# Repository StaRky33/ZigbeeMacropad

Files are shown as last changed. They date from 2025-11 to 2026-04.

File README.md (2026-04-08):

# 🧠 Zigbee Macropad (ESP32-C6)

A compact **16-key Zigbee macropad** powered by the an **ESP32-C6**, designed for integration with **Home Assistant (ZIGBEE2MQTT)**.  
It provides tactile mechanical key input, configurable LED feedback, and a fully 3D-printed case.
It gives 3 sorts of inputs, single click, double clicks and long click to add into any automation to control device remotely.

---

## ⚙️ Hardware

| Component | Description |
|---|---|
| **MCU** | Seeed Studio XIAO ESP32C6 |
| **Switches** | 16 x Cherry MX Red (linear) |
| **Battery** | 1 x 3.7V 1000mAh Lipo 603048 |
| **Button** | 6 mm tactile push button (BOOT / Reset) |
| **Power switch** | 13 mm by 8.5 mm on/off slide switch |
| **Magnets** | 4 x 10 mm × 2 mm neodymium discs |
| **Threaded inserts** | 5 x M2.5 heat-set brass inserts |
| **Screws** | 4 x M2.5 × 5 mm machine screws |
| **Didodes**| 16 x 1N4148 Small Signal Fast Switching Diodes |
| **External RGB Led**| 1 x 4 pins 5mm RGB Led Common Cathode |
| **220 ohm resistor**| 3 x 220 ohm resistor |
| **Case** | 3D-printed PLA enclosure (about 79g with cap switches and supports) |
| **Switches cap**| 16 x 3D-printed in PLA less than 18g total |

---

## 🧩 3D-Printed Parts

Designed and customized in **Tinkercad**, printed with **Centauri Carbon and transparent PLA**.  
Printed at 0.2 mm layer height, 15–20% infill, no supports required.

Files available on Github or in Printables [here](https://www.printables.com/model/1496778-zigbee-macropad-16-buttons-esp32c6) or Thingiverse [there](https://www.thingiverse.com/thing:7215442).

### 🔗 Remixed Models
- [16 Keys Macropad](https://www.printables.com/model/140766-16-keys-macropad)  
- [Simple Cherry MX Keycap](https://www.printables.com/model/118708-simple-cherry-mx-keycap)

---
### ⚡ Easy Install (Recommended)
No tools needed — flash directly from your browser:  
👉 [Web Flasher](https://starky33.github.io/ZigbeeMacropad)  
Works on Chrome and Edge only. Connect your ESP32-C6 via USB first.

## 💻 Code

Development began in **Arduino IDE**, later migrated to **VS Code with ESP-IDF v5.3.4** for Zigbee and multitasking support.

### 🧠 Software Stack
- **Framework:** ESP-IDF v5.3.4  
- **Zigbee SDK:** [Espressif ESP-Zigbee-SDK](https://github.com/espressif/esp-zigbee-sdk)  
- **Zigbee Role:** Router / End Device  
- **Endpoint Type:** Custom Endpoint and clusters

### 🔧 Functionality
- 16 GPIO-connected keys with **single**, **double**, and **long press** detection
- **LED feedback** color for each type of press  
- **LED feedback** brightness controlled via Zigbee “brightness” attribute  
- **BOOT button** triggers Zigbee factory reset and new pairing mode  
- **ON/OFF switch** physical button to turn everything off and recharge the batteries
- **Blinking red LED** indicates pairing state  
- **Debounce and ISR-driven** button logic for reliability  
- **Deep sleep** after 20 sec to save battery time  

---

## 🗺️ Circuit Schematic
[Link to circuit] (https://www.circuit-diagram.org/editor/c/4865aa39fb9b4097a776ca335299ee0a)

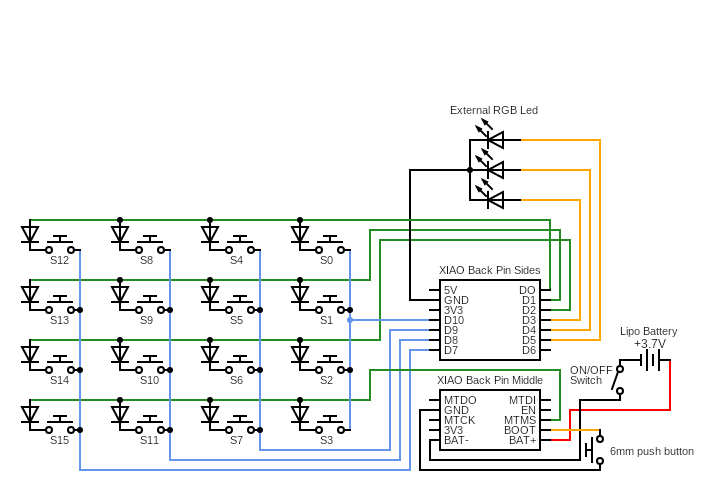
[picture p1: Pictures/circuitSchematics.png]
Circuit Schematics

---

## 💰 Price Breakdown
Calculated from **unit price × quantity used**:

| Item | Pack Price | Qty Used | Unit Cost | Cost Used |
|---|---|---|---|---|
| XIAO Esp32C6 | 8.04 € / 1 | 1 | 8.04 € | **8.04 €** |
| Mechanical Switches | 8.18 € / 20 | 16 | 0.41 € | **6.54 €** |
| Diodes 1N4148 | 1.20 € / 100 | 16 | 0.01 € | **0.19 €** |
| Magnets | 4.99 € / 50 | 4 | 0.10 € | **0.40 €** |
| M2.5 Inserts | 10.79 € / 600 | 5 | 0.018 € | **0.09 €** |
| Transparent PLA | 16.00 € / 1 kg | 100 g | 1.60 € | **1.60 €** |
| 6mm Push Button | 2.23 € / 50 | 1 | 0.045 € | **0.04 €** |
| ON/OFF Switch | 1.41 € / 5 | 1 | 0.28 € | **0.28 €** |
| 3.7V 1000mAh 603048 Lipo Battery  | 9.49 € / 3 | 1 | 3.16 € | **3.16 €** |
| External 5mm RGB Led Common Cathode | 1.29 € / 50 | 1 | 0.03 € | ** 0.03 €** |
| 220ohm resistore | 0,93€ / 100 | 3 | 0.028 € | ** 0.03 €** |
   
### **➡️ Total Cost per Macropad: 20.42 €**

---

## ⚠️ Note about the ESP32-C6 board

Using the Seeed Studio XIAO ESP32C6 is a breeze. 

The documentation is excellent.
The chip already contains a BMS so you can plug the battery directly in and charge it with USB-C

---

## 🧰 Build Instructions

### 🪛 1. Print and Prepare the Case
- Print all parts. Only the remix part is present in github, everything else can be found on printables.
- Verify that magnets, switches, and PCB fit snugly before final assembly.
- Insert **M2.5 heat-set inserts** into the designated mounting points using a soldering iron at ~200 °C.

### ⚡ 2. Mount the Components
- **Cherry MX switches**: press-fit into the 16-slot plate, solder to perfboard or PCB or with simple wires.
- **XIAO ESP32C6**: simply clip in place with any fixation. You might need to push a bit hard.
- **6 mm BOOT button**: mount to a small hole on the side (for Zigbee reset). Add some glue from glue gun.
- **Power switch**: connect inline with battery’s.
- **Battery holder**: Press fit battery inside. The EBL battery have a builtin BMS so I glue them in their slot with the micro usb accessible outside.
- **Magnets**: press-fit into the lid and base for a secure snap fit. You can add super glue to make sure they don't move.

### 🔋 3. Wiring Overview
| Connection | Description |
|---|---|
| **GPIO 0(D0),1(D1),2(D2),4(MTMS) and 18(D10),19(D9),20(D8),17(D7)** | 0,1,2,4 are for Rows, 18,19,20,17 are for Columns. Follow the wiring diagram. Connect 4 wires to columns and to one side of every switch. Connect all diodes to the other side of the switch. Make sure the black marker is connected to the switch and the other end is connected to the 3 other diodes on the same row. |
| **GPIO 9(BOOT)** | BOOT / Reset button. Connect to one side of the 6mm button and the other to GND. |
| **GPIO 21(D3),22(D4),23(D5)** | RGB Led is connected to 220 ohm resistor and to ground. The longest pin is ground. The side with a single pin it's R that goes into D5, then D4 for G, then D3 for B |
| **Battery pack** | Bat+ and Bat- on the ESP32 with bat + in line with the On/Off switch. |
| **On/Off switch** | Inline with battery lead. |

### 🔧 4. Flash the Firmware
1. Install **ESP-IDF v5.3.4** (or newer).  
2. Clone or copy the project to your workspace.  
3. Build and flash:
   ```bash
   idf.py set-target esp32c6
   idf.py build
   idf.py flash monitor
The device will start blinking red to indicate Zigbee pairing mode.

---

## 🔗 Pair with Home Assistant

Add macropad.mjs file to config/zigbee2mqtt/external_converters (if folder does not exist create it).
Then reboot Zigbee2MQTT in Settings/Add-ons/Zigbee2MQTT/Info and press Restart (takes 30 seconds)
In Home Assistant, open Settings → Devices & Services → Zigbee2MQTT → Permit join.
Test button clicks (single, double, hold) — LED flashes will reflect the button type.
You can now create an automation based on the button clicks.

The cluster ID is defined as a single constant `MACROPAD_CLUSTER` at the top 
of `macropad.mjs`. If it ever stops working after a z2m update, check the 
z2m logs for the cluster number and update that one constant.
To find your cluster name, simply check the logs in Zigbee2MQTT. I prefer checking them in the add-on directly since there is more information.
Add-on logs accessible in Settings/Add-ons/Zigbee2MQTT/Log

---

## ✨ Features Summary

🔘 16 mechanical switches with multiple click detection
🔋💤 Deep Sleep feature turning on after 2 minutes to save battery
💡 LED feedback brightness linked to Zigbee brightness setting
🔄 BOOT button triggers factory reset and re-pairing
🔴 Blinking red LED during pairing
🧱 Modular, 3D-printed enclosure with magnets and inserts
🪫 Battery powered with on/off switch

---

## 🧾 License

This project is released under the MIT License.
Remixed 3D models remain under their respective creator licenses (see linked Printables pages).

---

## 📸 Gallery

![Final project](Pictures/PXL_20251212_120048397.jpg)

![Internals](Pictures/PXL_20260106_132522850.jpg)

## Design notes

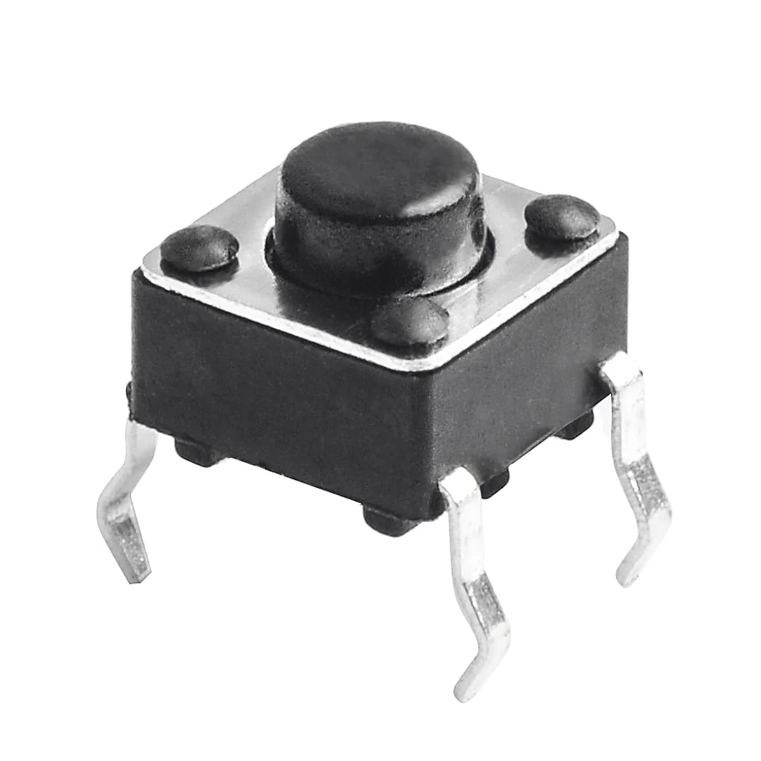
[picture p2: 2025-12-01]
Pictures/6mm push button.jpg

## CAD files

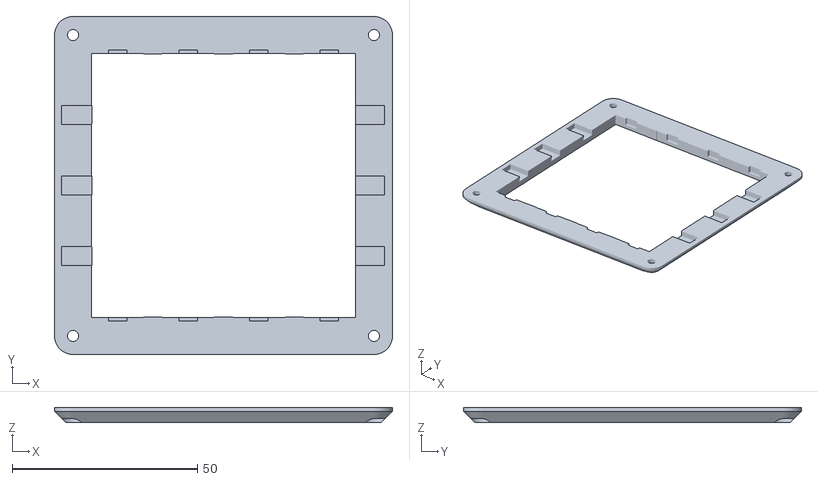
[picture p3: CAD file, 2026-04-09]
Models/ZigbeeMacropadTopCoverExteriorV2.stl
91.2 x 91.2 x 4.00

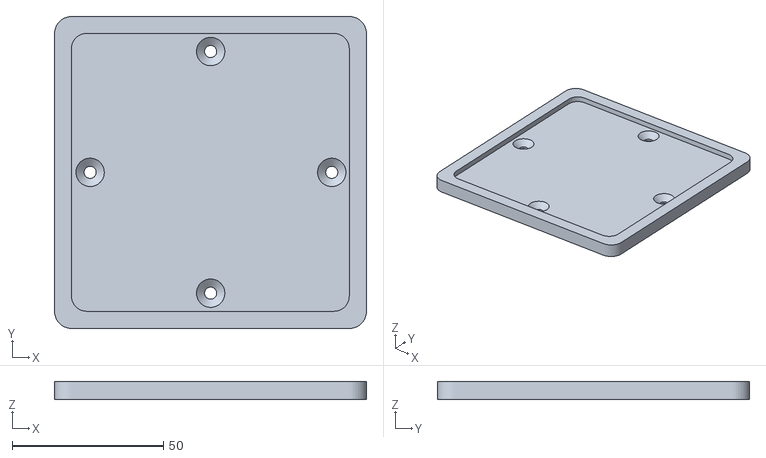
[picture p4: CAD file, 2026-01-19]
Models/ZigbeeMacropadBasePlateV4.stl
103.3 x 103.3 x 6.00

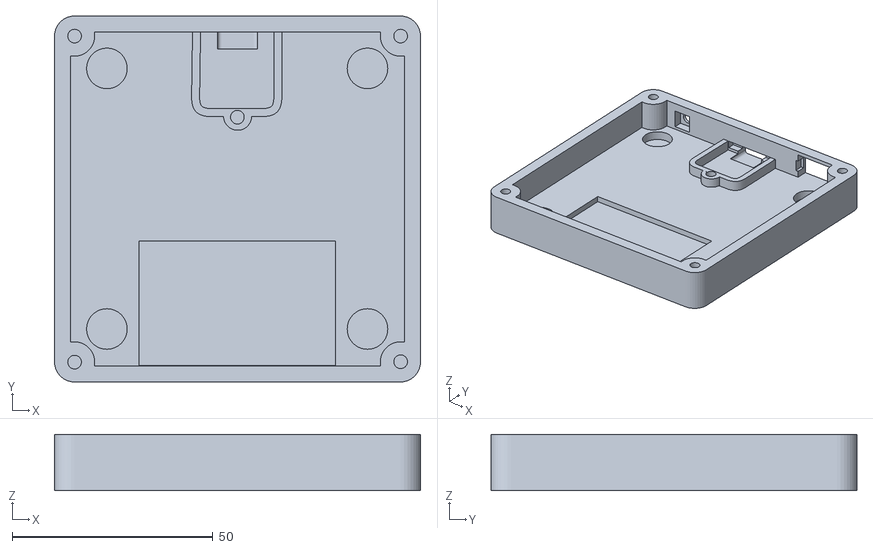
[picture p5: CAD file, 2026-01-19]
Models/ZigbeeMacropadXIAOV2.stl
91.2 x 91.1 x 14.0

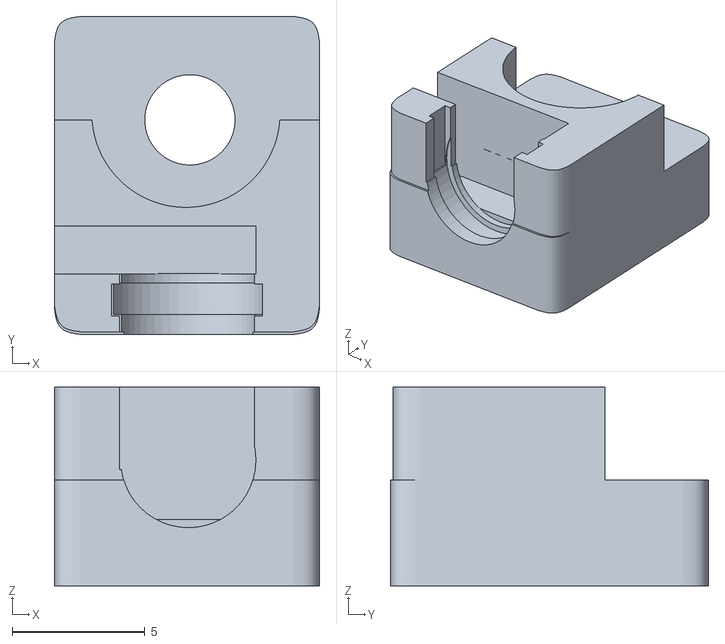
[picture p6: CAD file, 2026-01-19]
Models/ZigbeeMacropadClipXIAOV2.stl
10.0 x 12.0 x 7.50

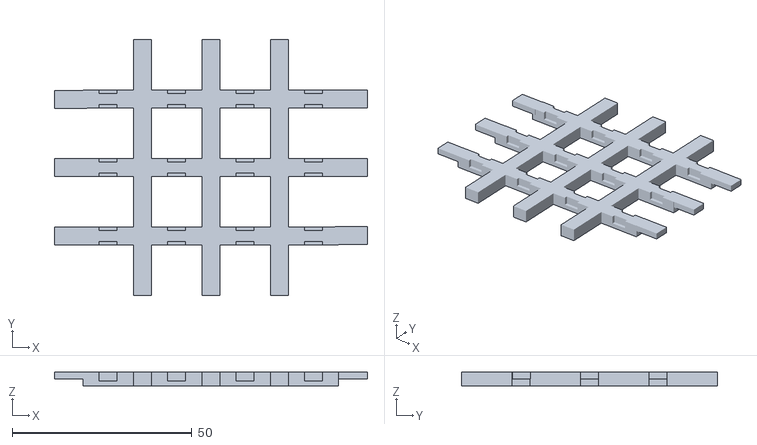
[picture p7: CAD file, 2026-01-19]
Models/ZigbeeMacropadTopCoverInterior.stl
87.0 x 71.1 x 4.00

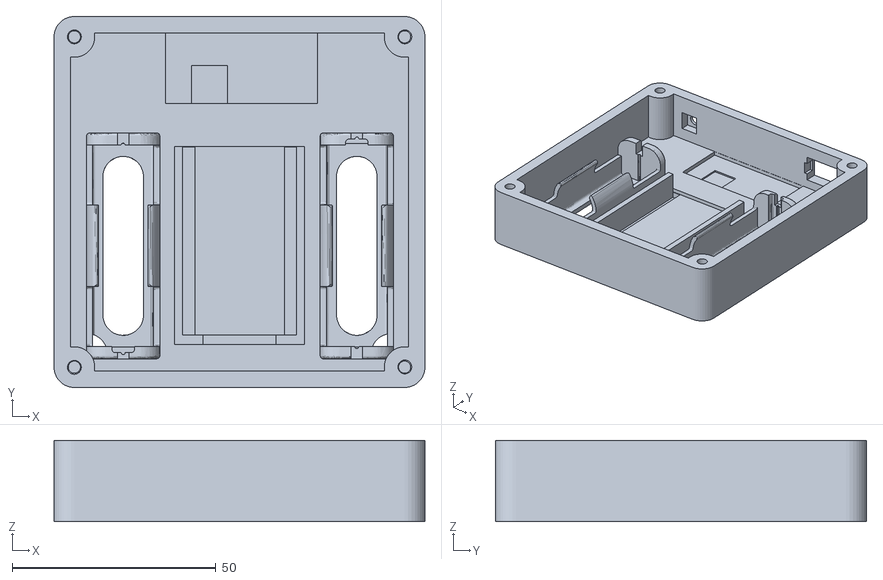
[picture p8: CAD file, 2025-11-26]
Models/ZigbeeMacropadBottomCoverV7.stl
91.1 x 91.2 x 20.0

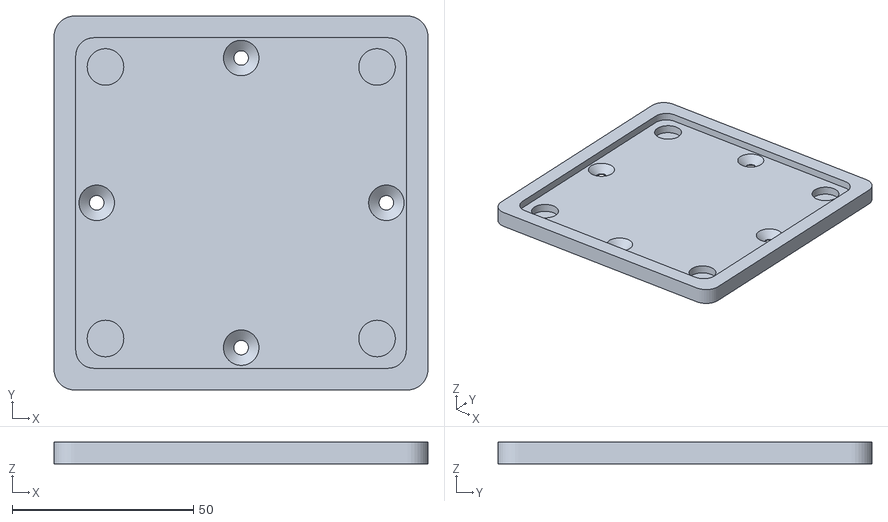
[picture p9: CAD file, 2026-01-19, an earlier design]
Models/ZigbeeMacropadBasePlateV2.stl
103.3 x 103.3 x 6.00

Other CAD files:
Models/ZigbeeMacropadXIAOV1.stl
Models/ZigbeeMacropadBasePlate.stl

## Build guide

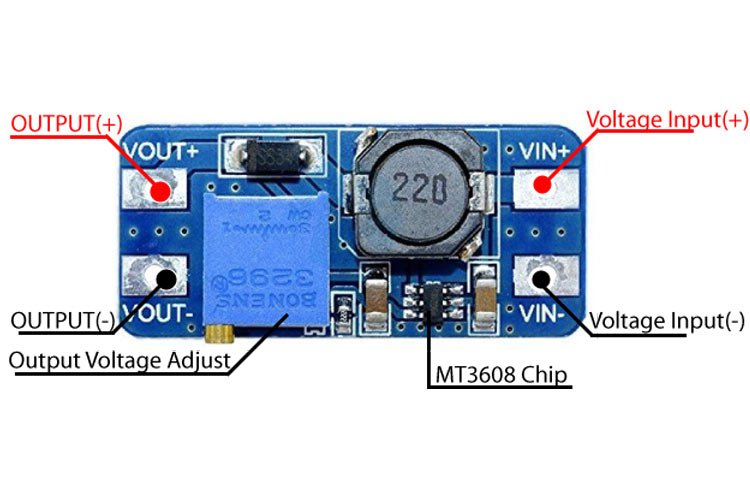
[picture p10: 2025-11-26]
Pictures/MT3608-Step-Up-Power-Module-Pinout.jpg

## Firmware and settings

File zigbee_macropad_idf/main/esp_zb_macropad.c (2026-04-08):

#include <stdio.h>
#include <string.h>
#include "esp_zb_macropad.h"
#include "esp_check.h"
#include "esp_log.h"
#include "esp_sleep.h"
#include "esp_timer.h"
#include "ha/esp_zigbee_ha_standard.h"
#include "nvs_flash.h"
#include "nvs.h"
#include "driver/gpio.h"
#include "freertos/FreeRTOS.h"
#include "freertos/task.h"
#include "freertos/queue.h"
#include "rgb_led.h"

#if !defined CONFIG_ZB_ZCZR
#error Define ZB_ZCZR in idf.py menuconfig to compile light (Router) source code.
#endif

#define TAG                 "MACROPAD"

/* --- PINS --------------------------------------------------------------- */
#define ROWS 4
#define COLS 4
#define BTN_COUNT (ROWS * COLS)

//Must be RST Pins (support deep sleep)
static const gpio_num_t ROW_PINS[ROWS] = {
    GPIO_NUM_0, GPIO_NUM_1, GPIO_NUM_2, GPIO_NUM_4,
}; //D0, D1, D2, MTMS

//Any available Pins
//White macropad GPIO_NUM_18, GPIO_NUM_20, GPIO_NUM_19, GPIO_NUM_17,
//Black macropad GPIO_NUM_17, GPIO_NUM_19, GPIO_NUM_20, GPIO_NUM_18,
static const gpio_num_t COL_PINS[COLS] = {
    GPIO_NUM_17, GPIO_NUM_19, GPIO_NUM_20, GPIO_NUM_18,
}; //D10, D9, D8, D7

//Native physical button button on board can still be connected with external button
//White macropad GPIO_NUM_16
//Black macropad GPIO_NUM_9
#define BOOT_BUTTON_GPIO     GPIO_NUM_9

/* --- Deep sleep variables -------------------------------------- */
#define INACTIVITY_SLEEP_MS   (120 * 1000)        // 1 minute --> 20sec test
#define INACTIVITY_SLEEP_US   (INACTIVITY_SLEEP_MS * 1000ULL)

static uint64_t g_last_activity_us = 0;

/* --- Timing (ms) for local keypad -------------------------------------- */
#define BTN_POLL_INTERVAL_MS   10
#define DEBOUNCE_MS        30
#define DOUBLE_CLICK_MS   400
#define HOLD_PRESS_MS    1000

/* --- Endpoint and clusters -------------------------------------- */
#define MACROPAD_ENDPOINT            0x01

/* Custom cluster used to report button events to Z2M */
#define MACROPAD_CLUSTER_ID          0xFF00
#define MACROPAD_CMD_BUTTON_EVENT    0x00

#define MACROPAD_ATTR_BRIGHTNESS_ID    0x0A00
/* Use all channels or restrict as you like */
#define ESP_ZB_PRIMARY_CHANNEL_MASK  ESP_ZB_TRANSCEIVER_ALL_CHANNELS_MASK

/* --- Steering -------------------------------------- */
#define STEERING_RETRY_DELAY_MS  2000
#define STEERING_MAX_RETRIES     5

static uint8_t g_steering_retries = 0;

/* --- Button state machine ----------------------------------------------- */
typedef struct {
    bool raw;
    bool stable;
    bool prev_stable;
    uint64_t last_change_us;
    uint64_t press_start_us;
    uint64_t last_release_us;
    bool hold_fired;
} btn_state_t;

typedef struct {
    uint8_t idx;       // which button (0–15)
    uint64_t timestamp_us;
    bool level;        // 0 = pressed, 1 = released
} btn_evt_t;

static QueueHandle_t s_boot_evt_q = NULL;

static btn_state_t g_btn[BTN_COUNT];

/* --- Zigbee + LED state ------------------------------------------------- */
static bool g_is_joined     = false;
static bool g_blinking      = false;
static bool g_blink_on      = false;
static bool g_zb_ready      = false;

/* Brightness (0..100 from Zigbee); used for key feedback */
static uint8_t g_brightness = 100;

/* --- Helpers ------------------------------------------------------------ */
static inline uint64_t now_us(void) { return esp_timer_get_time(); }

typedef enum { ACT_NONE, ACT_SINGLE, ACT_DOUBLE, ACT_HOLD } action_t;

/* --- Forward declarations  ------------------------------------------------------ */
static const char* action_str(action_t a);
static void flash_action(action_t a, uint8_t brightness);
static void start_network_steering(uint8_t param);
static void zb_blink_step(void);
static void zb_reset_and_steer_cb(void);

/* Prototypes */
static esp_err_t zb_attribute_handler(const esp_zb_zcl_set_attr_value_message_t *message);
static esp_err_t zb_action_handler(esp_zb_core_action_callback_id_t callback_id, const void *message);

/* Public helper to send a button event (call this from your key matrix code) */
void macropad_send_button_event(uint8_t button_id, action_t action);

/* ======================================================================= */
/*                          INIT GPIO                                      */
/* ======================================================================= */
static void matrix_gpio_init(void)
{
    // Rows: inputs with pull-up
    for (int r = 0; r < ROWS; ++r) {
        gpio_config_t io_conf = {
            .pin_bit_mask = 1ULL << ROW_PINS[r],
            .mode = GPIO_MODE_INPUT,
            .pull_up_en = GPIO_PULLUP_ENABLE,
            .pull_down_en = GPIO_PULLDOWN_DISABLE,
            .intr_type = GPIO_INTR_DISABLE,
        };
        gpio_config(&io_conf);
    }

    // Columns: outputs, start HIGH
    for (int c = 0; c < COLS; ++c) {
        gpio_config_t io_conf = {
            .pin_bit_mask = 1ULL << COL_PINS[c],
            .mode = GPIO_MODE_OUTPUT,
            .pull_up_en = GPIO_PULLUP_DISABLE,
            .pull_down_en = GPIO_PULLDOWN_DISABLE,
            .intr_type = GPIO_INTR_DISABLE,
        };
        gpio_config(&io_conf);
        gpio_set_level(COL_PINS[c], 1); // idle high
    }
}

/* ======================================================================= */
/*                          SLEEP                                          */
/* ======================================================================= */
static uint64_t build_row_wakeup_mask(void)
{
    uint64_t mask = 0;

    for (int r = 0; r < ROWS; ++r) {
        gpio_num_t gpio = ROW_PINS[r];

        // Optional sanity check: make sure this pin *can* be used for wake
        if (!esp_sleep_is_valid_wakeup_gpio(gpio)) {
            ESP_LOGE(TAG, "GPIO %d is not a valid deep sleep wake pin!", gpio);
        }
        mask |= (1ULL << gpio);  // BIT(gpio)
    }

    return mask;
}

static void load_brightness_from_nvs(void)
{
    nvs_handle_t h;
    if (nvs_open("macropad", NVS_READONLY, &h) == ESP_OK) {
        uint8_t val;
        if (nvs_get_u8(h, "brightness", &val) == ESP_OK) {
            g_brightness = val;
        }
        nvs_close(h);
    }
}

void macropad_enter_deep_sleep(void)
{
    ESP_LOGI(TAG, "Preparing to enter deep sleep...");

    // 1) Columns: outputs LOW so any pressed key can pull rows LOW via diodes
    for (int c = 0; c < COLS; ++c) {
        gpio_config_t col_conf = {
            .pin_bit_mask = 1ULL << COL_PINS[c],
            .mode = GPIO_MODE_OUTPUT,
            .pull_up_en = GPIO_PULLUP_DISABLE,
            .pull_down_en = GPIO_PULLDOWN_DISABLE,
            .intr_type = GPIO_INTR_DISABLE,
        };
        gpio_config(&col_conf);

        gpio_set_level(COL_PINS[c], 0);   // keep column LOW in deep sleep

        // Optional: hold this level through deep sleep
        gpio_hold_en(COL_PINS[c]);
    }

    // 2) Rows: inputs (no interrupts), we'll rely on wakeup logic instead
    for (int r = 0; r < ROWS; ++r) {
        gpio_config_t row_conf = {
            .pin_bit_mask = 1ULL << ROW_PINS[r],
            .mode = GPIO_MODE_INPUT,
            .pull_up_en = GPIO_PULLUP_ENABLE,    // keep them HIGH when idle
            .pull_down_en = GPIO_PULLDOWN_DISABLE,
            .intr_type = GPIO_INTR_DISABLE,
        };
        gpio_config(&row_conf);
    }

    // 3) Enable deep sleep wake on rows, triggered when they go LOW
    uint64_t wake_mask = build_row_wakeup_mask();

    esp_err_t err = esp_deep_sleep_enable_gpio_wakeup(
        wake_mask,
        ESP_GPIO_WAKEUP_GPIO_LOW     // wake when any selected GPIO turns LOW
    );
    if (err != ESP_OK) {
        ESP_LOGE(TAG, "Failed to enable GPIO wakeup (err=0x%x)", err);
    }

    ESP_LOGI(TAG, "Entering deep sleep, wake mask=0x%llx", (unsigned long long)wake_mask);

    // Optional: log flush
    vTaskDelay(pdMS_TO_TICKS(100));

    esp_deep_sleep_start();
    // never returns
}

/* ======================================================================= */
/*                          BLINKER (ZB CONTEXT)                           */
/* ======================================================================= */
static void zb_blink_step(void)
{
    if (!g_blinking) {
        if (g_blink_on) {                  // ensure off
            rgb_led_off();
            g_blink_on = false;
        }
        esp_zb_scheduler_alarm_cancel((esp_zb_callback_t)zb_blink_step, 0);
        return;
    }

    g_blink_on = !g_blink_on;
    if (g_blink_on) {
        rgb_led_set_rgb(255, 0, 0, g_brightness);
    } else {
        rgb_led_off();
    }

    /* Reschedule single instance */
    esp_zb_scheduler_alarm_cancel((esp_zb_callback_t)zb_blink_step, 0);
    esp_zb_scheduler_alarm((esp_zb_callback_t)zb_blink_step, 0, 300);
}

static void zb_stop_pairing_blink(void)
{
    g_blinking = false;
    if (g_blink_on) {
        rgb_led_off();
        g_blink_on = false;
    }
    esp_zb_scheduler_alarm_cancel((esp_zb_callback_t)zb_blink_step, 0);
}

/* ======================================================================= */
/*                   FACTORY RESET + COMMISSION (ZB CTX)                   */
/* ======================================================================= */
static void start_network_steering(uint8_t param)
{
    (void)param;
    esp_zb_bdb_start_top_level_commissioning(ESP_ZB_BDB_MODE_NETWORK_STEERING);
}

static void zb_reset_and_steer_cb(void)
{
    ESP_LOGW(TAG, "Factory reset: clearing Zigbee NVS and restarting commissioning...");
    g_is_joined = false;
    g_blinking  = true;

    esp_zb_factory_reset();

    /* Start fresh blink loop (single instance) */
    esp_zb_scheduler_alarm_cancel((esp_zb_callback_t)zb_blink_step, 0);
    esp_zb_scheduler_alarm((esp_zb_callback_t)zb_blink_step, 0, 0);

    /* Start network steering shortly after */
    esp_zb_scheduler_alarm(start_network_steering, 0, 1500);
}

/* ======================================================================= */
/*                      BOOT BUTTON (ISR + QUEUE)                          */
/* ======================================================================= */
static void IRAM_ATTR boot_button_isr(void *arg) {
    uint32_t dummy = 1;
    xQueueSendFromISR(s_boot_evt_q, &dummy, NULL);
}

static void boot_button_task(void *arg) {
    uint32_t dummy;
    while (1) {
        if (xQueueReceive(s_boot_evt_q, &dummy, portMAX_DELAY)) {
            if (g_zb_ready) {
                esp_zb_scheduler_alarm((esp_zb_callback_t)zb_reset_and_steer_cb, 0, 0);
            } else {
                ESP_LOGW(TAG, "Zigbee not ready; ignoring button press");
            }
        }
    }
}

/* ======================================================================= */
/*                     LOCAL FEEDBACK (color fixed)                        */
/* ======================================================================= */
static const char* action_str(action_t a) {
    return (a==ACT_SINGLE) ? "single" : (a==ACT_DOUBLE) ? "double" : "hold";
}

// Your action_t should already exist
// typedef enum { ACT_NONE, ACT_SINGLE, ACT_DOUBLE, ACT_HOLD } action_t;

static void flash_action(action_t a, uint8_t brightness_percent)
{
    /* If brightness is 0, skip visible flash */
    if (brightness_percent == 0) return;

    uint8_t r = 0, g = 0, b = 0;

    /* Fixed colors per action; only brightness comes from Zigbee */
    switch (a) {
        case ACT_SINGLE:
            // Example: green
            r = 0;   g = 255; b = 0;
            break;
        case ACT_DOUBLE:
            // Example: blue
            r = 0;   g = 0;   b = 255;
            break;
        case ACT_HOLD:
            // Example: yellow (R+G)
            r = 255; g = 255; b = 0;
            break;
        default:
            break;
    }

    /* Apply color + brightness */
    rgb_led_set_rgb(r, g, b, brightness_percent);

    vTaskDelay(pdMS_TO_TICKS(150));

    /* Turn off after flash */
    rgb_led_off();
}


static uint8_t level_to_pwm(uint8_t lvl) {
    const uint8_t max = 255; // or your PWM max
    return (uint8_t)((lvl * max) / 100);
}

static void on_button_action(uint8_t index, action_t act) {
    ESP_LOGI(TAG, "Button %u -> %s (feedback=%u)", (unsigned)index, action_str(act), (unsigned)g_brightness);
    flash_action(act, level_to_pwm(g_brightness));
    macropad_send_button_event(index, act);
}

/* ======================================================================= */
/*                        BUTTONS TASK                                     */
/* ======================================================================= */
// Fill raw_states[BTN_COUNT] with true if pressed, false otherwise
static void matrix_scan(bool raw_states[BTN_COUNT])
{
    // Clear all
    for (int i = 0; i < BTN_COUNT; ++i) {
        raw_states[i] = false;
    }

    for (int c = 0; c < COLS; ++c) {
        // Set all columns HIGH
        for (int cc = 0; cc < COLS; ++cc) {
            gpio_set_level(COL_PINS[cc], 1);
        }

        // Drive current column LOW (active)
        gpio_set_level(COL_PINS[c], 0);

        // Small settle delay (a few microseconds is enough)
        esp_rom_delay_us(5);

        for (int r = 0; r < ROWS; ++r) {
            int level = gpio_get_level(ROW_PINS[r]); // 0 = pressed (active low)
            bool pressed = (level == 0);

            int idx = r * COLS + c;  // mapping row/col -> button index
            raw_states[idx] = pressed;
        }
    }

    // Return columns to idle HIGH (optional but nice)
    for (int c = 0; c < COLS; ++c) {
        gpio_set_level(COL_PINS[c], 1);
    }
}

static void btn_state_reset(btn_state_t *b)
{
    memset(b, 0, sizeof(*b));
}

static void button_task(void *arg)
{
    
    const uint64_t debounce_us      = DEBOUNCE_MS * 1000ULL;
    const uint64_t double_click_us  = DOUBLE_CLICK_MS * 1000ULL;
    const uint64_t long_press_us    = HOLD_PRESS_MS * 1000ULL;

    bool raw_states[BTN_COUNT];
    while (true) {
        if(!g_is_joined)
        {
            vTaskDelay(pdMS_TO_TICKS(BTN_POLL_INTERVAL_MS));
            continue; // exit function if not connected to zigbee network.
        }
        uint64_t now = now_us();

        // 1. Scan whole matrix once -> raw_states[]
        matrix_scan(raw_states);
        
        // 2. Run your existing state machine per logical button
        for (int i = 0; i < BTN_COUNT; ++i) {
            bool raw = raw_states[i];    // <- instead of reading GPIO directly
            btn_state_t *b = &g_btn[i];

            // Debounce transition
            if (raw != b->stable && now - b->last_change_us > debounce_us) {
                b->prev_stable = b->stable;
                b->stable = raw;
                b->last_change_us = now;

                if (b->stable) {
                    // pressed
                    b->press_start_us = now;
                    b->hold_fired = false;
                } else {
                    // released
                    if (!b->hold_fired) {
                        if (b->last_release_us &&
                            (now - b->last_release_us < double_click_us)) {
                            on_button_action(i, ACT_DOUBLE);
                            g_last_activity_us = now;
                            b->last_release_us = 0;
                        } else {
                            b->last_release_us = now;
                        }
                    }
                }
            }

            // long press detection
            if (b->stable && !b->hold_fired &&
                now - b->press_start_us > long_press_us) {
                b->hold_fired = true;
                on_button_action(i, ACT_HOLD);
                g_last_activity_us = now;
                b->last_release_us = 0;
            }

            // single click confirmation (timeout expired)
            if (!b->stable && b->last_release_us &&
                now - b->last_release_us > double_click_us) {
                on_button_action(i, ACT_SINGLE);
                g_last_activity_us = now;
                b->last_release_us = 0;
            }
        }
        // 🔹 Inactivity check here
        if (now - g_last_activity_us > INACTIVITY_SLEEP_US) {
            ESP_LOGI(TAG, "No activity for %llu us, entering deep sleep",
                     (unsigned long long)(now - g_last_activity_us));
            macropad_enter_deep_sleep();
            // esp_deep_sleep_start() does not return
        }

        vTaskDelay(pdMS_TO_TICKS(BTN_POLL_INTERVAL_MS));
    }
}
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
void app_main(void)
{
    esp_sleep_wakeup_cause_t cause = esp_sleep_get_wakeup_cause();
    
    // Clear holds so we can reconfigure pins
    for (int c = 0; c < COLS; ++c) {
        gpio_hold_dis(COL_PINS[c]);
    }

    matrix_gpio_init();
    // Initialise button state array
    for (int i = 0; i < BTN_COUNT; ++i) {
        btn_state_reset(&g_btn[i]);
    }
    g_last_activity_us = now_us();
    
    if (cause == ESP_SLEEP_WAKEUP_GPIO) {
        // We woke because some row went LOW (button pressed).
        // Try to see which button(s) are still pressed *right now*.
        bool raw_states[BTN_COUNT];
        matrix_scan(raw_states);

        for (int i = 0; i < BTN_COUNT; ++i) {
            if (raw_states[i]) {
                btn_state_t *b = &g_btn[i];

                // Pretend this button is currently pressed
                b->stable         = true;
                b->prev_stable    = false;
                b->hold_fired     = false;
                b->press_start_us = g_last_activity_us;
                b->last_change_us = g_last_activity_us;
                b->last_release_us = 0;

                // You could log it for debugging:
                ESP_LOGI(TAG, "Woke with button %d pressed", i);
            }
        }
    }
    nvs_flash_init();
    load_brightness_from_nvs();

    ESP_LOGI(TAG, "Starting 16-button macropad");
    
    // --- Configure BOOT button input ---
    gpio_config_t btnio = {
        .pin_bit_mask = 1ULL << BOOT_BUTTON_GPIO,
        .mode = GPIO_MODE_INPUT,
        .pull_up_en = 1,
        .pull_down_en = 0,
        .intr_type = GPIO_INTR_NEGEDGE
    };
    ESP_ERROR_CHECK(gpio_config(&btnio));

    // --- Create queue ---
    s_boot_evt_q = xQueueCreate(4, sizeof(uint32_t));

    // --- Install ISR service ONCE ---
    ESP_ERROR_CHECK(gpio_install_isr_service(0));
    gpio_isr_handler_add(BOOT_BUTTON_GPIO, boot_button_isr, NULL);

    // --- Launch tasks ---
    xTaskCreate(button_task, "button_task", 4096, NULL, 1, NULL);
    xTaskCreate(boot_button_task, "boot_btn", 2048, NULL, 1, NULL);

    /* --- ZIGBEE --------------------------------------------------------- */
    ESP_ERROR_CHECK(nvs_flash_init());

    esp_zb_platform_config_t config = {
        .radio_config = ESP_ZB_DEFAULT_RADIO_CONFIG(),
        .host_config  = ESP_ZB_DEFAULT_HOST_CONFIG(),
    };
    ESP_ERROR_CHECK(esp_zb_platform_config(&config));

    xTaskCreate(esp_zb_task, "ZB_main", 8192, NULL, 5, NULL);        
    
    ESP_LOGI(TAG, "Ready.");
}

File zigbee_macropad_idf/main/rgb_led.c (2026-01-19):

#include "driver/ledc.h"
#include "driver/gpio.h"
#include "esp_log.h"

static const char *TAG = "RGB_LED";

/* GPIOs for RGB LED (common cathode, pin to GND) */
#define RGB_LED_R_GPIO   GPIO_NUM_21 // D3
#define RGB_LED_G_GPIO   GPIO_NUM_22 // D4
#define RGB_LED_B_GPIO   GPIO_NUM_23 // D5

/* LEDC config */
#define RGB_LED_LEDC_MODE      LEDC_LOW_SPEED_MODE
#define RGB_LED_LEDC_TIMER     LEDC_TIMER_0
#define RGB_LED_LEDC_FREQ_HZ   5000
#define RGB_LED_LEDC_RES       LEDC_TIMER_8_BIT  // 0..255
#define RGB_LED_DUTY_MAX       ((1 << 8) - 1)

/* Channels for R, G, B */
#define RGB_LED_CH_R   LEDC_CHANNEL_0
#define RGB_LED_CH_G   LEDC_CHANNEL_1
#define RGB_LED_CH_B   LEDC_CHANNEL_2

static bool s_rgb_led_inited = false;

esp_err_t rgb_led_init(void)
{
    if (s_rgb_led_inited) {
        return ESP_OK;
    }

    /* Timer */
    ledc_timer_config_t timer_cfg = {
        .speed_mode       = RGB_LED_LEDC_MODE,
        .duty_resolution  = RGB_LED_LEDC_RES,
        .timer_num        = RGB_LED_LEDC_TIMER,
        .freq_hz          = RGB_LED_LEDC_FREQ_HZ,
        .clk_cfg          = LEDC_AUTO_CLK,
    };
    ESP_ERROR_CHECK(ledc_timer_config(&timer_cfg));

    /* Channels */
    ledc_channel_config_t ch_cfg = {
        .speed_mode     = RGB_LED_LEDC_MODE,
        .timer_sel      = RGB_LED_LEDC_TIMER,
        .duty           = 0,
        .hpoint         = 0,
        .intr_type      = LEDC_INTR_DISABLE,
    };

    ch_cfg.channel = RGB_LED_CH_R;
    ch_cfg.gpio_num = RGB_LED_R_GPIO;
    ESP_ERROR_CHECK(ledc_channel_config(&ch_cfg));

    ch_cfg.channel = RGB_LED_CH_G;
    ch_cfg.gpio_num = RGB_LED_G_GPIO;
    ESP_ERROR_CHECK(ledc_channel_config(&ch_cfg));

    ch_cfg.channel = RGB_LED_CH_B;
    ch_cfg.gpio_num = RGB_LED_B_GPIO;
    ESP_ERROR_CHECK(ledc_channel_config(&ch_cfg));

    s_rgb_led_inited = true;
    ESP_LOGI(TAG, "RGB LED initialized on R=%d G=%d B=%d",
             RGB_LED_R_GPIO, RGB_LED_G_GPIO, RGB_LED_B_GPIO);
    return ESP_OK;
}

/* brightness_percent: 0..100
 * r/g/b: 0..255
 */
void rgb_led_set_rgb(uint8_t r, uint8_t g, uint8_t b, uint8_t brightness_percent)
{
    if (!s_rgb_led_inited) {
        rgb_led_init();
    }

    if (brightness_percent == 0) {
        r = g = b = 0;
    }

    /* Scale by brightness and PWM resolution */
    uint32_t scale = (uint32_t)brightness_percent;
    uint32_t duty_r = (uint32_t)r * scale * RGB_LED_DUTY_MAX / (255U * 100U);
    uint32_t duty_g = (uint32_t)g * scale * RGB_LED_DUTY_MAX / (255U * 100U);
    uint32_t duty_b = (uint32_t)b * scale * RGB_LED_DUTY_MAX / (255U * 100U);

    ESP_ERROR_CHECK(ledc_set_duty(RGB_LED_LEDC_MODE, RGB_LED_CH_R, duty_r));
    ESP_ERROR_CHECK(ledc_update_duty(RGB_LED_LEDC_MODE, RGB_LED_CH_R));

    ESP_ERROR_CHECK(ledc_set_duty(RGB_LED_LEDC_MODE, RGB_LED_CH_G, duty_g));
    ESP_ERROR_CHECK(ledc_update_duty(RGB_LED_LEDC_MODE, RGB_LED_CH_G));

    ESP_ERROR_CHECK(ledc_set_duty(RGB_LED_LEDC_MODE, RGB_LED_CH_B, duty_b));
    ESP_ERROR_CHECK(ledc_update_duty(RGB_LED_LEDC_MODE, RGB_LED_CH_B));
}

/* Convenience: turn LED fully off */
void rgb_led_off(void)
{
    rgb_led_set_rgb(0, 0, 0, 0);
}

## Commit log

2025-11-24 Create cluster for button and send event when pressed.
2025-11-24 Fix button detection for all types + clean hold namings for long press.
    [esp_zb_macropad.c]
2025-11-24 Invert columns and row to fix wiring issue.
    [esp_zb_macropad.c]
2025-11-24 Redo wiring to allow deepsleep.
2025-11-26 Create new housing with 2 battery and MT3608
    [ZigbeeMacropadBottomCoverV7.stl]
2025-11-26 Add schematics + components picture + remove old readme
2025-11-26 Update readme with schematics
2025-12-01 Add latest images and base plate model.
    [ZigbeeMacropadBasePlate.stl]
2025-12-01 Basic changes to support XIAO Esp32C6.
    [ZigbeeMacropadClipXIAO.stl, ZigbeeMacropadXIAOV1.stl]
2025-12-01 Create custom driver for external RGB Led.
2025-12-01 Fix pairing blinking and remove unused light driver code.
    [esp_zb_macropad.c]
2025-12-01 Updated circuit.
2025-12-15 Add model + comments with pin name
    [ZigbeeMacropadBasePlateV2.stl, ZigbeeMacropadClipXIAO.stl, ZigbeeMacropadClipXIAOV2.stl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]
2025-12-16 Update README.md
    Update readme with 1N4148 diodes and better wiring explanation.
2025-12-17 updated pictures. Missing only battery.
2026-01-19 Lastest project pictures and models
    [ZigbeeMacropadBasePlateV4.stl, ZigbeeMacropadXIAOV2.stl]
2026-04-08 Fix cluster name to avoid conflict with Philips clusters.
    [esp_zb_macropad.c]
2026-04-08 Fix steering issues
2026-04-09 Fix ZigbeeMacropadTopCoverExterior model + Add pictures
    [ZigbeeMacropadTopCoverExterior.stl, ZigbeeMacropadTopCoverExteriorV2.stl]
